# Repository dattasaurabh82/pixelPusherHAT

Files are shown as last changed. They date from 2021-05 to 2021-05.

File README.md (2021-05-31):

## PixelPusherHAT
Based on [hzeller's HW hat design](https://github.com/hzeller/rpi-rgb-led-matrix/tree/dfc27c15c224a92496034a39512a274744879e86/adapter/active-3) in the footprint of a HAT, designed in Eagle with minor modifications.

### [The schematic](/assetsREF/PixelPusherV0.pdf)

The managed library for Eagle and Fusion 360 can be found [here](https://library.io/libraries/29033116-PixelPusherV0): 

### _Note_: The GERBERs were generated using [jlcpcb's cam script](https://support.jlcpcb.com/article/137-how-to-generate-gerber-and-drill-files-in-autodesk-eagle).

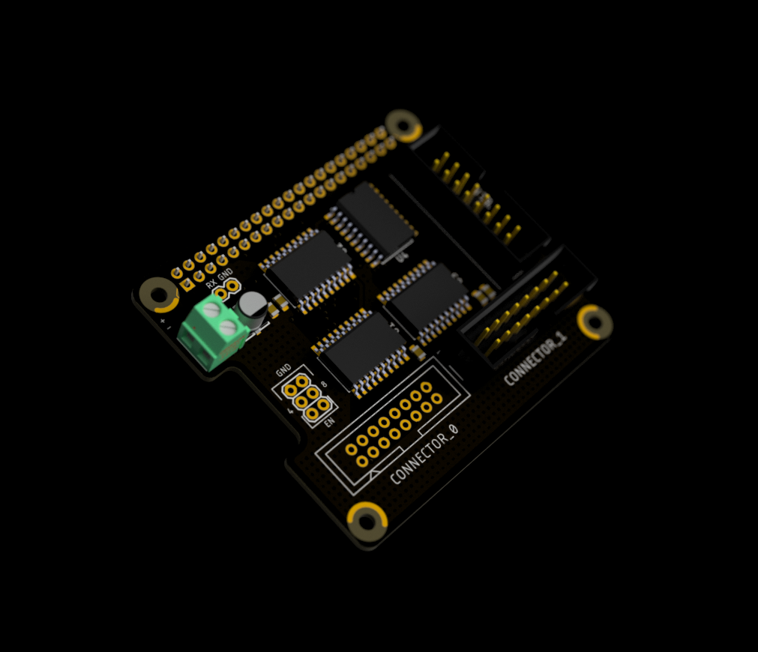
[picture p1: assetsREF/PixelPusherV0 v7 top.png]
top image

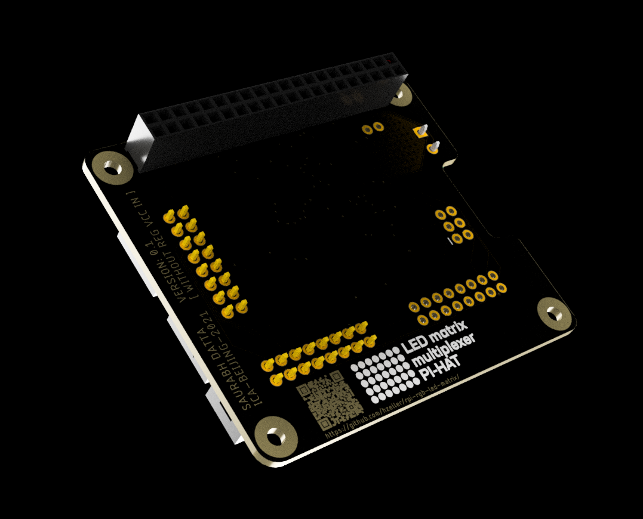
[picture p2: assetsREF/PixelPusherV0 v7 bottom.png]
bottom image


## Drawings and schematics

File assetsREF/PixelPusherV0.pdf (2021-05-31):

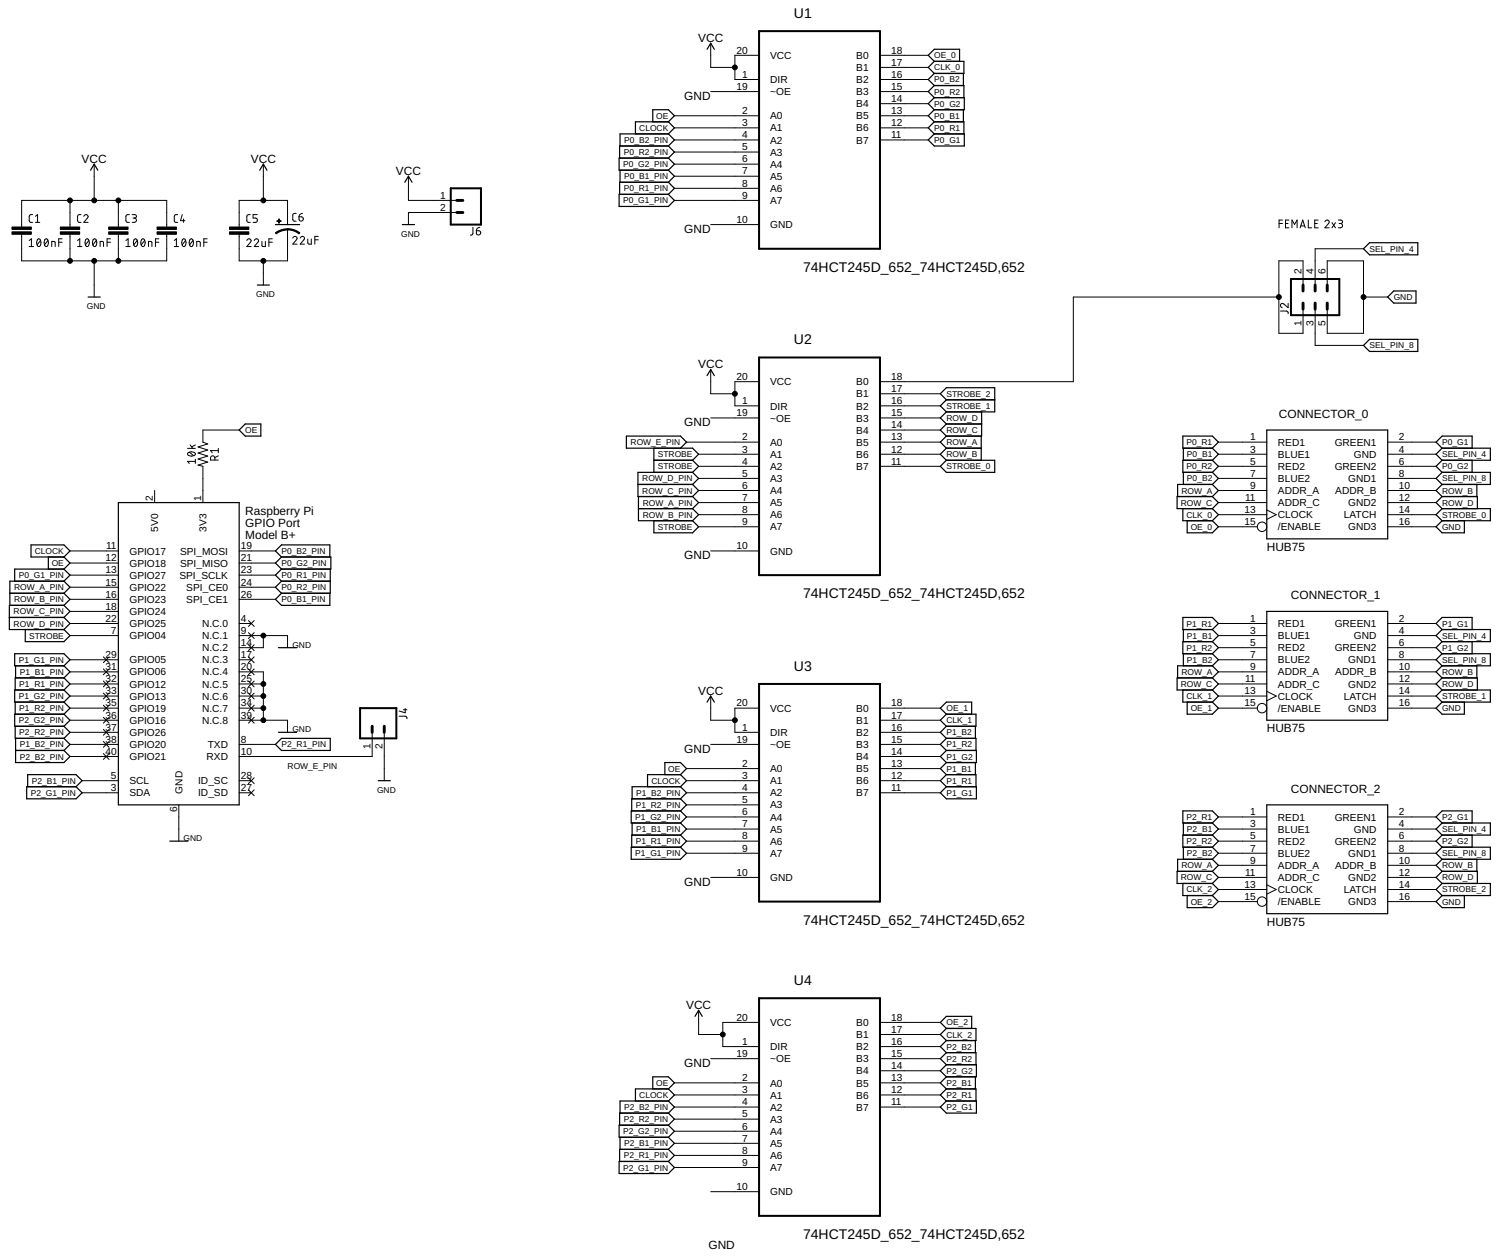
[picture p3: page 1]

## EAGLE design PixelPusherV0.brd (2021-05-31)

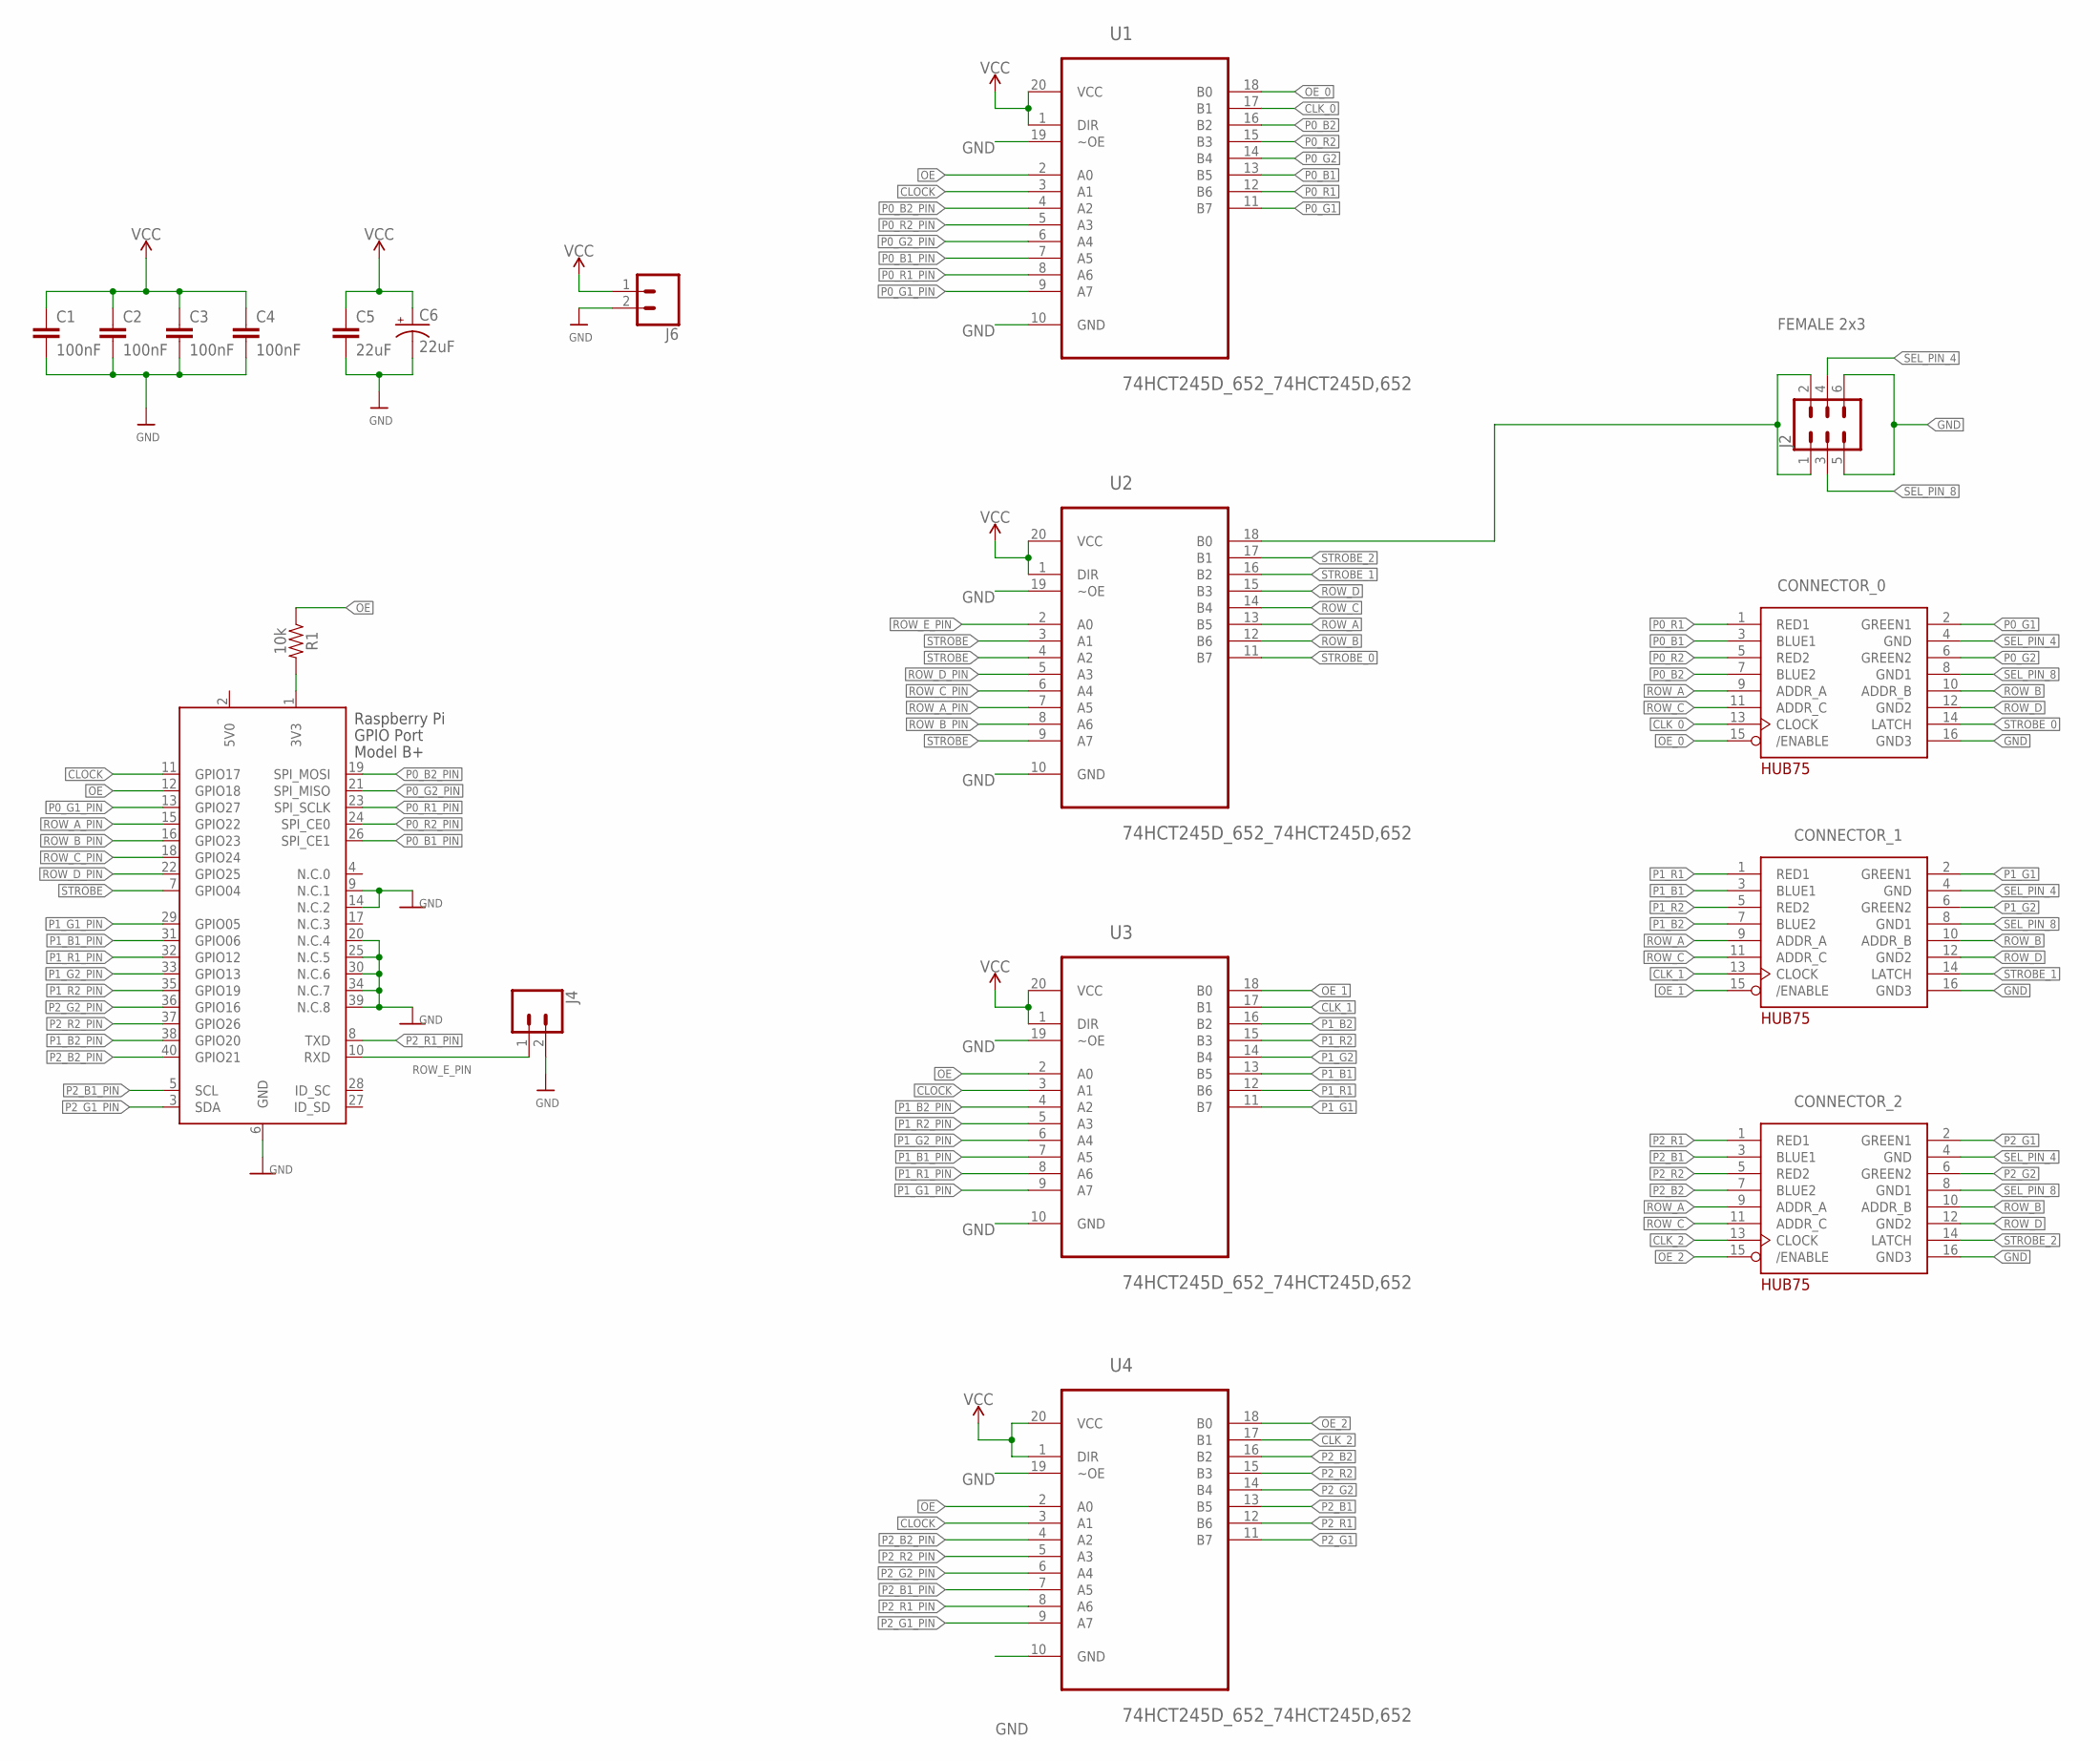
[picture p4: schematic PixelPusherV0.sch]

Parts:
C1, C2, C3, C4: 100nF; SPARKFUN-CAPACITORS_0603
C5: 22uF; SPARKFUN-CAPACITORS_0805
C6: 22uF; SPARKFUN-CAPACITORS_PANASONIC_C
CONNECTOR_0, CONNECTOR_1, CONNECTOR_2: ADAFRUIT_HUB75MATRIX; ADAFRUIT_2X08-IDC
J2: FEMALE 2x3; SPARKFUN-CONNECTORS_2X3
J4: SPARKFUN-CONNECTORS_CONN_02; SPARKFUN-CONNECTORS_1X02
J6: SPARKFUN-CONNECTORS_CONN_023.5MM_LOCK; SPARKFUN-CONNECTORS_SCREWTERMINAL-3.5MM-2_LOCK
R1: 10k; SPARKFUN-RESISTORS_0603:1
U1, U2, U3, U4: 74HCT245D_652_74HCT245D,652; 74HCT245D_652_SOIC127P1032X265-20N
X2: RASPBERRYPI_BASTELSTUBE_V13_RASPI_BOARD_B+_HD; RASPBERRYPI_BASTELSTUBE_V13_RASPI_BOARD_B+HAT_DF

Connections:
5V0: X2.2 (5V0)
CLK_0: CONNECTOR_0.13 (CLOCK), U1.17 (B1)
CLK_1: CONNECTOR_1.13 (CLOCK), U3.17 (B1)
CLK_2: CONNECTOR_2.13 (CLOCK), U4.17 (B1)
CLOCK: U1.3 (A1), U3.3 (A1), U4.3 (A1), X2.11 (GPIO17)
GND: C1.2, C2.2, C3.2, C4.2, C5.2, C6.-, CONNECTOR_0.16 (GND3), CONNECTOR_1.16 (GND3), CONNECTOR_2.16 (GND3), J2.5, J2.6, J4.2, J6.2, U1.10 (GND), U1.19 (~OE), U2.10 (GND), U2.19 (~OE), U3.10 (GND), U3.19 (~OE), U4.10 (GND), U4.19 (~OE), X2.6 (GND), X2.9 (N.C.1), X2.14 (N.C.2), X2.20 (N.C.4), X2.25 (N.C.5), X2.30 (N.C.6), X2.34 (N.C.7), X2.39 (N.C.8)
unnamed: J2.1, J2.2, U2.18 (B0)
unnamed: R1.2, X2.1 (3V3)
OE: R1.1, U1.2 (A0), U3.2 (A0), U4.2 (A0), X2.12 (GPIO18)
OE_0: CONNECTOR_0.15 (/ENABLE), U1.18 (B0)
OE_1: CONNECTOR_1.15 (/ENABLE), U3.18 (B0)
OE_2: CONNECTOR_2.15 (/ENABLE), U4.18 (B0)
P0_B1: CONNECTOR_0.3 (BLUE1), U1.13 (B5)
P0_B1_PIN: U1.7 (A5), X2.26 (SPI_CE1)
P0_B2: CONNECTOR_0.7 (BLUE2), U1.16 (B2)
P0_B2_PIN: U1.4 (A2), X2.19 (SPI_MOSI)
P0_G1: CONNECTOR_0.2 (GREEN1), U1.11 (B7)
P0_G1_PIN: U1.9 (A7), X2.13 (GPIO27)
P0_G2: CONNECTOR_0.6 (GREEN2), U1.14 (B4)
P0_G2_PIN: U1.6 (A4), X2.21 (SPI_MISO)
P0_R1: CONNECTOR_0.1 (RED1), U1.12 (B6)
P0_R1_PIN: U1.8 (A6), X2.23 (SPI_SCLK)
P0_R2: CONNECTOR_0.5 (RED2), U1.15 (B3)
P0_R2_PIN: U1.5 (A3), X2.24 (SPI_CE0)
P1_B1: CONNECTOR_1.3 (BLUE1), U3.13 (B5)
P1_B1_PIN: U3.7 (A5), X2.31 (GPIO06)
P1_B2: CONNECTOR_1.7 (BLUE2), U3.16 (B2)
P1_B2_PIN: U3.4 (A2), X2.38 (GPIO20)
P1_G1: CONNECTOR_1.2 (GREEN1), U3.11 (B7)
P1_G1_PIN: U3.9 (A7), X2.29 (GPIO05)
P1_G2: CONNECTOR_1.6 (GREEN2), U3.14 (B4)
P1_G2_PIN: U3.6 (A4), X2.33 (GPIO13)
P1_R1: CONNECTOR_1.1 (RED1), U3.12 (B6)
P1_R1_PIN: U3.8 (A6), X2.32 (GPIO12)
P1_R2: CONNECTOR_1.5 (RED2), U3.15 (B3)
P1_R2_PIN: U3.5 (A3), X2.35 (GPIO19)
P2_B1: CONNECTOR_2.3 (BLUE1), U4.13 (B5)
P2_B1_PIN: U4.7 (A5), X2.5 (SCL)
P2_B2: CONNECTOR_2.7 (BLUE2), U4.16 (B2)
P2_B2_PIN: U4.4 (A2), X2.40 (GPIO21)
P2_G1: CONNECTOR_2.2 (GREEN1), U4.11 (B7)
P2_G1_PIN: U4.9 (A7), X2.3 (SDA)
P2_G2: CONNECTOR_2.6 (GREEN2), U4.14 (B4)
P2_G2_PIN: U4.6 (A4), X2.36 (GPIO16)
P2_R1: CONNECTOR_2.1 (RED1), U4.12 (B6)
P2_R1_PIN: U4.8 (A6), X2.8 (TXD)
P2_R2: CONNECTOR_2.5 (RED2), U4.15 (B3)
P2_R2_PIN: U4.5 (A3), X2.37 (GPIO26)
ROW_A: CONNECTOR_0.9 (ADDR_A), CONNECTOR_1.9 (ADDR_A), CONNECTOR_2.9 (ADDR_A), U2.13 (B5)
ROW_A_PIN: U2.7 (A5), X2.15 (GPIO22)
ROW_B: CONNECTOR_0.10 (ADDR_B), CONNECTOR_1.10 (ADDR_B), CONNECTOR_2.10 (ADDR_B), U2.12 (B6)
ROW_B_PIN: U2.8 (A6), X2.16 (GPIO23)
ROW_C: CONNECTOR_0.11 (ADDR_C), CONNECTOR_1.11 (ADDR_C), CONNECTOR_2.11 (ADDR_C), U2.14 (B4)
ROW_C_PIN: U2.6 (A4), X2.18 (GPIO24)
ROW_D: CONNECTOR_0.12 (GND2), CONNECTOR_1.12 (GND2), CONNECTOR_2.12 (GND2), U2.15 (B3)
ROW_D_PIN: U2.5 (A3), X2.22 (GPIO25)
ROW_E_PIN: J4.1, U2.2 (A0), X2.10 (RXD)
SEL_PIN_4: CONNECTOR_0.4 (GND), CONNECTOR_1.4 (GND), CONNECTOR_2.4 (GND), J2.4
SEL_PIN_8: CONNECTOR_0.8 (GND1), CONNECTOR_1.8 (GND1), CONNECTOR_2.8 (GND1), J2.3
STROBE: U2.3 (A1), U2.4 (A2), U2.9 (A7), X2.7 (GPIO04)
STROBE_0: CONNECTOR_0.14 (LATCH), U2.11 (B7)
STROBE_1: CONNECTOR_1.14 (LATCH), U2.16 (B2)
STROBE_2: CONNECTOR_2.14 (LATCH), U2.17 (B1)
VCC: C1.1, C2.1, C3.1, C4.1, C5.1, C6.+, J6.1, U1.1 (DIR), U1.20 (VCC), U2.1 (DIR), U2.20 (VCC), U3.1 (DIR), U3.20 (VCC), U4.1 (DIR), U4.20 (VCC)

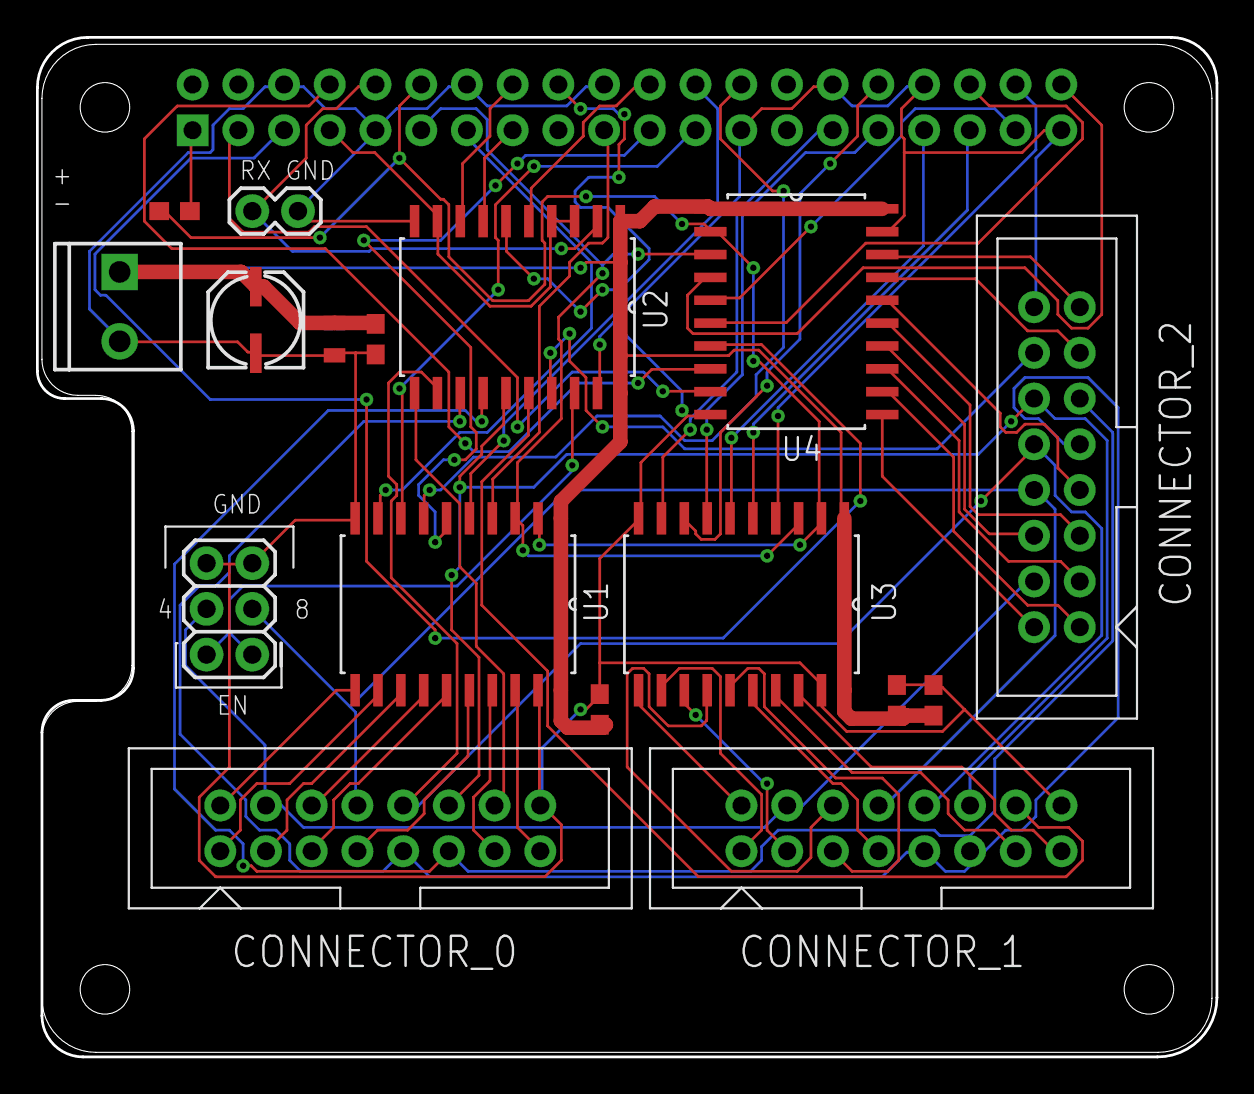
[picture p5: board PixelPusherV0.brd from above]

Board: 2 copper layers, 65.5 x 56.6 mm, 18 parts (0 on the bottom side), 63 nets.

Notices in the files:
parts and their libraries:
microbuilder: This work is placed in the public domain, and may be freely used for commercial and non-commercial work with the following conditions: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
